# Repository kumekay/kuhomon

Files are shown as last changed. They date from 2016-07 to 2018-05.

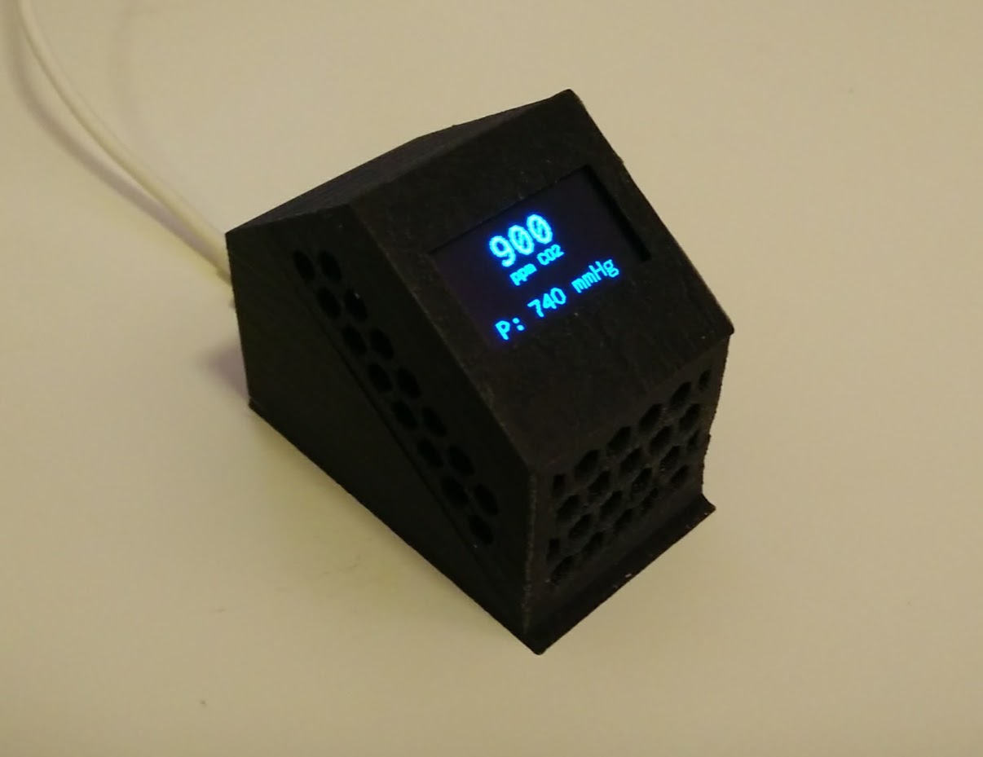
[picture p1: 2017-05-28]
demo.jpg

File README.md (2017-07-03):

# Kumekay Home Monitoring Device

System for measurement CO2/Humidity/Temperature/Pressure with OLED display and data upload through WiFi

If you want to use BME280 instead of SI7021+BMP085 take a look on [BME280 branch](https://github.com/pinya/kuhomon/tree/bme280)

## Discussion


## Components

- CO2 Sensor MH-Z19
- ESP8266 (NodeMCU ESP12+ based)
- SSD1306 0.96" 128x64 i2c OLED. Library: <https://github.com/olikraus/u8g2>
- Humidity/Temperature SI7021 i2c. Library: <https://github.com/LowPowerLab/SI7021>
- Pressure/Temperature BMP085 i2c. Library: <https://github.com/adafruit/Adafruit-BMP085-Library>

## Case

Model for printing kuhomon_case.stl

Known issues:
- To fit system to this case you have to use short wires
- Temperature measurements seems to be higher due to heat from ESP8266

## TODO
- Add offline support (show data on screen without WiFi)

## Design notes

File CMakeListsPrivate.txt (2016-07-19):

set(ENV{PATH} "/home/ku/.local/bin:/home/ku/bin:/home/ku/.rbenv/shims:/home/ku/.rbenv/bin:/home/ku/.local/bin:/home/ku/bin:/home/ku/.rbenv/shims:/home/ku/.rbenv/bin:/usr/local/sbin:/usr/local/bin:/usr/sbin:/usr/bin:/sbin:/bin:/usr/games:/usr/local/games:/snap/bin")
set(PLATFORMIO_CMD "/usr/local/bin/platformio")

include_directories("$ENV{HOME}/.platformio/packages/framework-arduinoespressif/variants/generic")
include_directories("$ENV{HOME}/.platformio/packages/framework-arduinoespressif/variants/nodemcu")
include_directories("$ENV{HOME}/.platformio/packages/framework-arduinoespressif/cores/esp8266")
include_directories("$ENV{HOME}/.platformio/packages/framework-arduinoespressif/cores/esp8266/libb64")
include_directories("$ENV{HOME}/.platformio/packages/framework-arduinoespressif/cores/esp8266/spiffs")
include_directories("$ENV{HOME}/.platformio/packages/framework-arduinoespressif/cores/esp8266/umm_malloc")
include_directories("$ENV{HOME}/.platformio/packages/framework-arduinoespressif/libraries/ESP8266WiFi/src")
include_directories("$ENV{HOME}/.platformio/packages/framework-arduinoespressif/libraries/ESP8266WiFi/src/include")
include_directories("$ENV{HOME}/.platformio/packages/framework-arduinoespressif/libraries/DNSServer/src")
include_directories("$ENV{HOME}/.platformio/packages/framework-arduinoespressif/libraries/ESP8266WebServer/src")
include_directories("$ENV{HOME}/.platformio/packages/framework-arduinoespressif/libraries/ESP8266WebServer/src/detail")
include_directories("$ENV{HOME}/.platformio/lib/WifiManager_ID567")
include_directories("$ENV{HOME}/.platformio/packages/framework-arduinoespressif/libraries/ESP8266HTTPClient/src")
include_directories("$ENV{HOME}/.platformio/packages/framework-arduinoespressif/libraries/ESP8266httpUpdate/src")
include_directories("$ENV{HOME}/.platformio/lib/Blynk_ID415/Adapters")
include_directories("$ENV{HOME}/.platformio/lib/Blynk_ID415/Blynk")
include_directories("$ENV{HOME}/.platformio/lib/Blynk_ID415")
include_directories("$ENV{HOME}/.platformio/lib/Blynk_ID415/utility")
include_directories("$ENV{HOME}/.platformio/lib/Json_ID64")
include_directories("$ENV{HOME}/.platformio/lib/Json_ID64/include")
include_directories("$ENV{HOME}/.platformio/lib/Json_ID64/include/ArduinoJson")
include_directories("$ENV{HOME}/.platformio/lib/Json_ID64/include/ArduinoJson/Internals")
include_directories("$ENV{HOME}/.platformio/lib/Json_ID64/include/ArduinoJson/Polyfills")
include_directories("$ENV{HOME}/.platformio/lib/Json_ID64/include/ArduinoJson/TypeTraits")
include_directories("$ENV{HOME}/.platformio/lib/Json_ID64/src/Internals")
include_directories("$ENV{HOME}/.platformio/lib/Json_ID64/src")
include_directories("$ENV{HOME}/.platformio/packages/framework-arduinoespressif/libraries/Wire")
include_directories("$ENV{HOME}/.platformio/packages/framework-arduinoespressif/libraries/SPI")
include_directories("$ENV{HOME}/Dropbox/kuhomon/lib/TFT_ILI9163C")
include_directories("$ENV{HOME}/Dropbox/kuhomon/lib/TFT_ILI9163C/_display")
include_directories("$ENV{HOME}/Dropbox/kuhomon/lib/TFT_ILI9163C/_fonts")
include_directories("$ENV{HOME}/Dropbox/kuhomon/lib/TFT_ILI9163C/_includes")
include_directories("$ENV{HOME}/Dropbox/kuhomon/lib/TFT_ILI9163C/_settings")
include_directories("$ENV{HOME}/.platformio/lib/Adafruit_DHT_ID19")
include_directories("$ENV{HOME}/.platformio/lib/SimpleTimer_ID419")
include_directories("$ENV{HOME}/.platformio/packages/framework-arduinoespressif/tools/sdk/include")
include_directories("$ENV{HOME}/.platformio/packages/framework-arduinoespressif/tools/sdk/lwip/include")
include_directories("$ENV{HOME}/Dropbox/kuhomon/src")
include_directories("$ENV{HOME}/.platformio/lib/Adafruit_BMP085_Unified_ID16")
include_directories("$ENV{HOME}/.platformio/lib/Adafruit_GFX_ID13")
include_directories("$ENV{HOME}/.platformio/lib/Adafruit_PCD8544_ID81")
include_directories("$ENV{HOME}/.platformio/lib/Adafruit_Unified_Sensor_ID31")
include_directories("$ENV{HOME}/.platformio/lib/Esp8266Configuration_ID227")
include_directories("$ENV{HOME}/.platformio/lib/Nanopb_ID431")
include_directories("$ENV{HOME}/.platformio/lib/PubSubClient_ID89/src")
include_directories("$ENV{HOME}/.platformio/lib/RTC_ID274/src")
include_directories("$ENV{HOME}/.platformio/lib/Task_ID272/src")
include_directories("$ENV{HOME}/.platformio/packages/framework-arduinoespressif/libraries/ArduinoOTA")
include_directories("$ENV{HOME}/.platformio/packages/framework-arduinoespressif/libraries/EEPROM")
include_directories("$ENV{HOME}/.platformio/packages/framework-arduinoespressif/libraries/ESP8266AVRISP/src")
include_directories("$ENV{HOME}/.platformio/packages/framework-arduinoespressif/libraries/ESP8266HTTPUpdateServer/src")
include_directories("$ENV{HOME}/.platformio/packages/framework-arduinoespressif/libraries/ESP8266SSDP")
include_directories("$ENV{HOME}/.platformio/packages/framework-arduinoespressif/libraries/ESP8266WiFiMesh/src")
include_directories("$ENV{HOME}/.platformio/packages/framework-arduinoespressif/libraries/ESP8266mDNS")
include_directories("$ENV{HOME}/.platformio/packages/framework-arduinoespressif/libraries/Ethernet/src")
include_directories("$ENV{HOME}/.platformio/packages/framework-arduinoespressif/libraries/GDBStub/src")
include_directories("$ENV{HOME}/.platformio/packages/framework-arduinoespressif/libraries/Hash/src")
include_directories("$ENV{HOME}/.platformio/packages/framework-arduinoespressif/libraries/SD/src")
include_directories("$ENV{HOME}/.platformio/packages/framework-arduinoespressif/libraries/Servo/src")
include_directories("$ENV{HOME}/.platformio/packages/framework-arduinoespressif/libraries/SoftwareSerial")
include_directories("$ENV{HOME}/.platformio/packages/framework-arduinoespressif/libraries/TFT_Touch_Shield_V2")
include_directories("$ENV{HOME}/.platformio/packages/framework-arduinoespressif/libraries/Ticker")
include_directories("$ENV{HOME}/.platformio/packages/framework-arduinoespressif/libraries/esp8266/src")
include_directories("$ENV{HOME}/.platformio/packages/toolchain-xtensa/xtensa-lx106-elf/include")
include_directories("$ENV{HOME}/.platformio/packages/toolchain-xtensa/lib/gcc/xtensa-lx106-elf/4.8.2/include")
include_directories("$ENV{HOME}/.platformio/packages/toolchain-xtensa/lib/gcc/xtensa-lx106-elf/4.8.2/include-fixed")

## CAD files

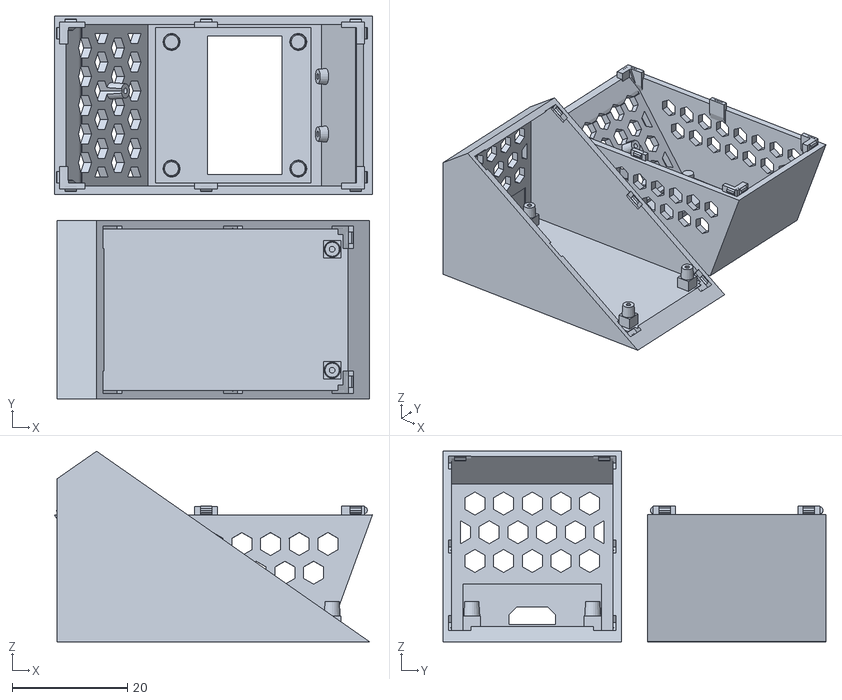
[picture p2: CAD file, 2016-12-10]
kuhomon_case.stl
55.2 x 66.5 x 33.1

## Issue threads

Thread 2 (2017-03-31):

плата висит в состоянии Loading...

zigithu, 2017-03-31:
Собрал схему только с одним датчиком (CO2 mh-z19). Загружается, по wifi доступна, на 192.168.4.1 заходит, но после конфигурирования параметров wifi плата перезагружается и висит в состоянии Loading...
В чем может быть причина? Возможно отсутствие датчиков приводит к зависанию? Возможно ли добавить проверку на отсутствие/смерть датчиков?

pinya, 2017-04-07:
Можете подключиться к serial консоле и прислать все, что выводится в процессе загрузки?

zigithu, 2017-04-10:
пока вот такие данные. Изменение кодировки не помогает
======================================
pio device monitor --port COM9 --baud 74880
--- Miniterm on COM9  74880,8,N,1 ---
--- Quit: Ctrl+C | Menu: Ctrl+T | Help: Ctrl+T followed by Ctrl+H ---

 ets Jan  8 2013,rst cause:2, boot mode:(3,6)

load 0x4010f000, len 1384, room 16
tail 8
chksum 0x2d
csum 0x2d
v09f0c112
~ld

pio device monitor --port COM9 --baud 115200
--- Miniterm on COM9  115200,8,N,1 ---
--- Quit: Ctrl+C | Menu: Ctrl+T | Help: Ctrl+T followed by Ctrl+H ---
r$␀dܞ|␀�l�|␃␌␌␄�␜�l�␌#|��␃�␓��|2c�␌#�p~�o�dno���␌#␜p��bd`␃rlp�o�␐␂␌␄�␄l␄��␌␄␌B␌N�|␂l�␌␄�p␄��oN�␃$��l ␃�␓2no␌d`␃␏␃or����␂␄␌b␌�␎$␎{��N␌␄#␄�␏l�␂l���␛$�$`␃��o�␃

pio device monitor --port COM9 --baud 9600
--- Miniterm on COM9  9600,8,N,1 ---
--- Quit: Ctrl+C | Menu: Ctrl+T | Help: Ctrl+T followed by Ctrl+H ---
␁␅^��␝q��

pinya, 2017-04-13:
Это нормальный вывод при загрузке, удивительно, что это все.
Отсутствие датчика CO2 и температуры/влажности не должно быть проблемой - просто будут возвращаться нули.
При отсутствии BMP в консоли должна быть строка `"Could not find a valid BMP085 sensor, check wiring!"`

Попробуйте, пожалуйста, еще раз собрать вывод консоли - не отключая плату от usb нажмите кнопку reset на плате. Вероятно там будет что-то еще
Скорость UART 115200

В начале там будет каша от загрузчика, он работает на другой скорости, но потом должен появиться вывод самой прошивки

Добавьте для проверки DEBUG_SERIAL.println("Start init...");` после строчки `        DEBUG_SERIAL.begin(115200);` в функции setup

zigithu, 2017-04-14:
Результат тот же. Дополнительной информации не появилось. При перезагрузке вываливает кучу мусора. При этом экран загорается и отображает стартовую станицу. Через веб то пускает то не пускает. В случае когда пускает: после указания учетных данных wifi сети подключается в точке доступа, на экране горит loading... и ничего не происходит.
Решил пока не мучить эту плату а подожду когда приедет esp-07. Попробую на ней.

pandability, 2017-05-22:
**zigithu**, у вас что нибудь получилось с этой или с новой платой? У меня такая же ситуация - после настройки wi-fi подключения плата висит в статусе Loading.

pandability, 2017-05-22:
Что то внятное выдало тоже только на скорости 74880, один раз увидел что boot mode:(3,7) было.

```
PORT OPEN 74880

Communication with MCU..Got answer! Communication with MCU established.
AutoDetect firmware...

Can't autodetect firmware, because proper answer not received (may be unknown firmware).
Please, reset module or continue.

 ets Jan  8 2013,rst cause:2, boot mode:(3,6)

load 0x4010f000, len 1384, room 16
tail 8
chksum 0x2d
csum 0x2d
v09f0c112
~ld
```

zigithu, 2017-05-23:
Заказал 2 платы на чипе 340.... жду больше месяца. Но я использовал свою NodeMCU в другом проекте и она там тоже работает, но очень нестабильно.
Следовательно она неисправна. но глюк плавающий - возможно надо пропаять и прогреть все контакты
PS
1)вот этот модуль глючит (v2) https://ru.aliexpress.com/item/New-Wireless-module-NodeMcu-Lua-WIFI-Internet-of-Things-development-board-based-ESP8266-with-pcb-Antenna/32593655688.html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
2) вот эти я ожидаю https://ru.aliexpress.com/item/ESP8266-CH340G-CH340-G-NodeMcu-V3-Lua-Wireless-WIFI-Module-Connector-Development-Board-Based-ESP-12E/32800966224.html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

pinya, 2017-05-23:
У меня есть несколько разных модулей, попробую на этой неделе повторить такое поведение

pinya, 2017-05-28:
Я совсем забыл, что в опубликованной версии кода для отладочной информации испльзуется другой serial порт, и нужен был еще один usb-uart, чтобы эти данные собирать.
Я это изменил (72074ee), теперь данные выводятся в основную консоль. Я не знаю есть ли проблема, описанная в этом issue, но по крайней мере debug вывод сейчас работает.
Завтра посмотрю подробнее.

pinya, 2017-06-01:
Я обновил код теперь он выводит больше информации в консоль и более детально отображает статус на экране + некоторые мелкие правки, которые вероятно решили проблему, поэтому прошу попробовать последнюю версию: 02580683aca0164042c28912a3c59f0fa347836b

zigithu, 2017-06-06:
Так, пришло время закрывать этот тикет. Мне наконец-то пришли мои платы (https://ru.aliexpress.com/item/ESP8266-CH340G-CH340-G-NodeMcu-V3-Lua-Wireless-WIFI-Module-Connector-Development-Board-Based-ESP-12E/32800966224.html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) они оказались абсолютно исправные за исключением того что судя по всему в них установлена более медленная флеш память не QUAD а DIO (вот тут можно посмотреть мой скриншот при прошивке через ESP Flash Tool). Как оказалось это не оригинальный AI-Thinker  а клон HYSIRY. Но тем не менее он работает. Я прошился прошивкой из ветки BME280. Как и **apan65** (https://github.com/pinya/kuhomon/issues/4) я попался на том что не указал blynk-токен. Для исправления ситуации в 421 строку вставил factoryReset(); перепрошился, потом убрал factoryReset(); и перепрошился еще раз. Датчик BME280 заработал отлично: показывает температуру влажность и атмосферное давление. А вот датчик Co2 я сжег когда перепаивал ему ноги(((((
PS 1) логи стали очень информативные. смотрятся на скорости 115200.
2) возможно на дисплей надо вывести тоже что и в консоли? сейчас:  drawBoot("Connecting...");         DEBUG_SERIAL.println("Connecting to blynk...");
сделать:  drawBoot("Connecting to blynk ...");         DEBUG_SERIAL.println("Connecting to blynk...");
или не влезет на экран?
3) в ветке BME280 не хватает библиотеки 166 и я так понимаю ненужные библиотеки: 536,525,16
Спасибо за ваш код. Было интересно. Пойду заказывать датчик(

pinya, 2017-07-03:
Рад, что у вас все получилось!

Closed 2017-07-03.

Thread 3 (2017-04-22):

bme-280 и датчик пыли GP2Y1014AU0F

kashaev, 2017-04-22:
Что необходимо поменять в коде, если я буду использовать bme-280 и датчик пыли GP2Y1014AU0F.

pinya, 2017-04-24:
А можно поподробнее в чем проблема? Кажется вы забыли добавить текст

pinya, 2017-04-24:
Если верить официальной схеме от sharp и вот этой инструкции, то вам еще понадобится резистор на 150 ом, и электролитический конденсатор на 220 мкФ (10в)
arduinodev.woofex.net/2012/12/01/standalone-sharp-dust-sensor

kashaev, 2017-04-25:
Прошу прощения, что трачу Ваше время. Насчёт необходимых элементов я понял. В ближайшее время приобрету.

pinya, 2017-05-19:
@kashaev добрый день, как успехи с модификацией? Что-нибудь вышло?

pinya, 2017-06-01:
@kashaev Если вы отказались от идеи делать версию с датчиком пыли, то я закрою этот вопрос

kashaev, 2017-06-12:
Здравствуйте! Очень много дел на работе и остается совсем мало свободного времени.. На данный момент я осваиваю азы программирования.  С 19 числа вплотную займусь этим вопросом. Все необходимые комплектующие у меня есть. Спасибо, что интересуетесь)

kashaev, 2017-06-28:
Здравствуйте! Прошу Вашего совета. Прибор собран, датчик пыли работает исправно. Проблема заключается в том, что он крайне не чувствителен. Нужно как следует дунуть в отверстие, чтоб он показал какие - либо цифры. Не калибровал. Есть идя поставить под него или на него что-то вроде кулера для тяги. Второй вопрос по поводу CO2: датчик показывает неадекватные значения, легко сбивается. Работает нормально только после повторной прошивки, но если выключить и включить снова сбивается. Не калибровал.

pinya, 2017-06-29:
По поводу датчика пыли не могу сказать, т.к. никогда им не пользовался. Он у вас с вентилятором для активной продувки или без?
Датчик CO2 имеет время прогрева около 3-5 минут, соответственно после включения первое время он показывает не совсем то. Если он у вас находится в квартире с периодическим проветриванием, то калибровать его не нужно.

kashaev, 2017-10-02:
Здравствуйте! Подскажите, пожалуйста,  можно ли самому создать приложение на ios, чтоб дублировать туда данные , приходящие на blynk? Элементарное одностраничное приложение, где будут просто показываться данные. Конструкторов приложений масса, но как их связать...

kumekay, 2017-10-02:
Можно из скетча отправлять данные не только в blynk, но и в какой-нибудь другой сервис при помощи http запроса. Вариантов слишком много, но какой-либо в пару кликов в голову не приходит. (я никогда не интересовался конструкторами приложение)
И еще вопрос в том, чем приложение blynk не подходит

kashaev, 2017-10-02:
Blynk подходит. Идея в том, что бы создать приложение немного с другим функционалом для группы людей, используя эти данные. Спасибо!

kumekay, 2017-10-02:
Ок, тогда будем считать этот вопрос закрытым

Closed 2017-10-02.

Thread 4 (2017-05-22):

Код для модификации с одним bme280 вместо пары bmp280+si702

pandability, 2017-05-22:
Добрый день.
Не будете ли вы столь любезны выложить вариант кода при использовании датчика BME280?
В силу того, что желание познакомиться с IoT возникло исключительно благодаря вашей статье про метеостанцию на GT, собственных сил и знаний пока не хватает.

pinya, 2017-05-23:
Добрый день, да я подготовлю вариант на этой неделе

apan65, 2017-05-24:
**pinya**, Отлично, как раз хотел сейчас с этим же вопросом обратиться. Буду ждать.

pinya, 2017-05-28:
Я пока не опубликовал этот вариант, т.к. навожу порядок в коде основной ветки. Сделаю в ближайшие несколько дней, после завершения #2

apan65, 2017-05-29:
C нетерпением ожидаю

pinya, 2017-06-01:
Опубликовал версию для BME280 в отдельной ветке:
https://github.com/pinya/kuhomon/tree/bme280

На руках у меня BME280 нет, чтобы проверить, но должно работать

apan65, 2017-06-01:
Такая беда
"IP address: 192.169.1.107
Load config...
Config loaded
blynk server: blynk-cloud.com
port: 8442
token: Blynk token
Connecting to blynk...
Connecting to blynk...
Connecting to blynk...
и тд, не может приконнектиться.
"

apan65, 2017-06-01:
Может это проблема роутера, с портами что-то?

pinya, 2017-06-01:
Проблема:
```
token: Blynk token
```
При настройке не указан токен blynk

Нужно сбросить на заводские настройки,
Вообще, Для сброса на заводские настройки нужно на время подсоединить GPIO 12 (D6) на землю, но здесь этот метод не сработает.
Я подумаю как это можно обойти.

Простая перепрошивка не поможет.

apan65, 2017-06-01:
> но здесь этот метод не сработает.
А чем вообще сброс теоретически может помочь и почему здесь этот метод не работает?

pinya, 2017-06-02:
При обычной перепрошивке данные подключения не удалятся, они хранятся в другой части памяти.
Как я уже писал, есть предусмотренный в прошивке метод для сброса на заводские настройки,

> Для сброса на заводские настройки нужно на время подсоединить GPIO 12 (D6) на землю,

Но этот метод не очень корректно организован, он работает, когда устройство полностью загружено. Здесь же оно останавливается в процессе загрузки.

Чтобы не ждать моего полноценного решения добавьте первой строкой в main.cpp в функцию `setup()` (строка 415) вызов   `factoryReset();`

```
void setup() {
  factoryReset();
```

Прошейте, подождите минутку,
потом удалите эту строчку и прошейте снова.
Это сработает

apan65, 2017-06-02:
Так, теперь работает, но с BME по нулям получает. Я его отдельно проверял, сенсор в порядке, может проблема с пинами?

pinya, 2017-06-02:
Я обновил код, можете прошить и прислать что он выводит в консоль после загрузки, при каждом измерении?

В моем случае:
```
Getting Temperature from SI7021
Getting Temperature from BMP085
Getting Humidity from SI7021
Getting Pressure from BMP085
Getting CO2
CO2:400
H: 41%
T: 28C
P: 742mmHg
CO2: 400ppm
```

apan65, 2017-06-02:
Всё так же
```
Getting Temperature from BME280
Getting Humidity from BME280
Getting Pressure from BME280
Getting CO2
CO2:710
H: 0.00%
T: 0.00C
P: 0.00mmHg
CO2: 710ppm

```

pinya, 2017-06-02:
Попробуйте сменить адрес в инициализации устройства. BME280 может работать на разных адресах.
в строке 439 укажите адрес 0x76 (по умолчанию 0x77)
```
        // Init Pressure/Temperature sensor
        if (!bme.begin(0x76)) {
                DEBUG_SERIAL.println("Could not find a valid BME280 sensor, check wiring!");
        }
```

Если это не поможет, то попробуйте посмотреть на каких адресах у вас вообще есть устройства,
это можно сделать при помощи вот этой прошивки:
https://playground.arduino.cc/Main/I2cScanner
Она выведет все i2c устройства в консоль

apan65, 2017-06-02:
Таки да, в адресе была проблема.

pinya, 2017-06-02:
Отлично, можно закрывать этот вопрос?

apan65, 2017-06-02:
Ага, огромное спасибо за помощь и идею для устройства.
Потом может парочка идей придет по улучшению функционала, отпишусь.

pinya, 2017-06-02:
Да, тут есть над чем поработать. Вероятно займусь новой версией в июле.
Удачи и спасибо за отзыв!

Closed 2017-06-02.

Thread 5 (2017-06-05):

BME280 в README.md

zigithu, 2017-06-05:
В ветке BME280 наверно в README.md

надо это
Humidity/Temperature SI7021 i2c. Library: https://github.com/LowPowerLab/SI7021
Pressure/Temperature BMP085 i2c. Library: https://github.com/adafruit/Adafruit-BMP085-Library

заменить вот на это
Humidity/Pressure/Temperature BME280        https://github.com/adafruit/Adafruit_BME280_Library

pinya, 2017-06-06:
Fixed in ee02863fa61568b8e211c38b9fcd5c51b8efa89d

Closed 2017-06-06.

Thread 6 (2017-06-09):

Добавить на главном экране иконки доступности блинка и подключения к wifi

pinya, 2017-06-09:
Добавить на главном экране иконки доступности блинка и подключения к wifi
при установлении связи иконки постоянно отображаются
При подключении к wifi вместо connecting wifi просто поморгать иконкой wifi
При подключении к blynk вместо connecting… просто поморгать иконкой blynk

zigithu, 2017-06-10:
к примеру вот так
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

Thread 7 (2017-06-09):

Отображать все значения на одном экране

kumekay, 2017-06-09:
Не очень удобно ждать около 10 секунд что бы увидеть все три текущих значения (T/P/H). Было бы круто увидеть все цифры на одном экране (без надобности ожидания пока обновится экран).
К примеру значения CO2 можно переместить в левую часть экрана а в правой части разместить в колонку все три значения (T/P/H)
примерно вот так
Wifi =ok blynk=ok
567 T= 23 oC
ppm CO2 H= 48%
P=739 mmHg

zigithu, 2017-06-10:
я имел ввиду что-то вроде этого:
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
Но лично для меня это уже не очень актуально - так как я планирую использовать датчик без дисплея.

kumekay, 2017-11-12:
Думаю, что этот вопрос можно закрыть

Closed 2017-11-12.

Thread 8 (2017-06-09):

Add offline support (show data on screen without WiFi)

pinya, 2017-06-09:

CadilVB, 2018-01-16:
Безусловно, автономная работа метеостанции сделает устройство функционально законченным.
Я реализовал режим автономной работы по алгоритму, который, как мне кажется, лежит  на поверхности:
ЕСЛИ  на заданном  pin'е  есть "1",  ТО автономная работа ИНАЧЕ работа в сети.
Этот алгоритм реализован в прилагаемом скетче.
В SETUP идентифицируются функции автономной работы по условию  if (digitalRead(display_pin) == HIGH) ...  else  ... идентификация функций  работы в сети. Аналогично по такому же условию вызываются функции в LOOP. Впрочем, из кода все станет понятно.
Скетч - работающий.  Достаточно подключить экран. Обратите внимание на пины подключения экрана. Датчики подключать не нужно - для тестирования работырежимов  заданы фиксированные значения  температуры, влажности и т.д.
Есть идея, как  автономную поддержку организовать более элегантно, но об этом поговорим позже, если будет интерес к теме ...
[OLED_Blynk_ON-OFF-line_1fin.zip](https://github.com/kumekay/kuhomon/files/1635117/OLED_Blynk_ON-OFF-line_1fin.zip)
...

kumekay, 2018-01-18:
Оффлайн режим лучше включать по таймауту при неудачи подключения к WiFi
Большая просьба, если хотите поделиться каким-нибудь кодом, то не прикладывайте его в zip-файлах, а создайте форк репозитория и внесите изменения туда,
или хотя бы на https://gist.github.com

nakuts, 2019-05-04:
Приветствую автора этого замечательного проекта, решил зделать ваш проект используя вашу статью на: https://habr.com/ru/post/400975/ "Код прошивки, чтобы не ходить на Github" скопировал и внёс в ардуино ide.
Даже получилось подобрать все библиотеки но в коде выдаёт ошибку: в строкеStaticJsonBuffer<200>
...................................
error: StaticJsonBuffer is a class from ArduinoJson 5. Please see arduinojson.org/upgrade to learn how to upgrade your program to ArduinoJson version 6
 StaticJsonBuffer<200> jsonBuffer;
DynamicJsonBuffer is a class from ArduinoJson 5. Please see arduinojson.org/upgrade to learn how to upgrade your program to ArduinoJson version 6
DynamicJsonBuffer jsonBuffer;
....................................

В платформео тоже не получилось докачать библиотеки
Помогите с проектом. :)

kumekay, 2019-05-06:
Попробуйт установить ArduinoJson версии 5, https://arduinojson.org/v5/doc/installation/

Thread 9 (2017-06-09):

Fix factory reset during setup()

pinya, 2017-06-09:

DimsterTim, 2018-02-04:
Я пробую повторить проект с BME280 и экраном ssd1306 32x128. Столкнулся со следующими проблемами. Не могу сбросить сохраненные токен Блинка и настроек WiFi. Как это сделать простейшим образом? При подключении к WiFi экран работает? А то у меня ничего не отображается.

DimsterTim, 2018-02-04:
Подключился к Блинку, в порт выдает только CO2, и то с ошибкой:
Getting Temperature from BME280
Getting Humidity from BME280
Getting Pressure from BME280
Getting CO2
CO2: Header not found
H: 0.00%
T: 0.00C
P: 0.00mmHg
CO2: 647ppm

kumekay, 2018-02-04:
> ssd1306 32x128

Точно не могу сказать какие проблемы могут быть из-за другого рамера экрана

> BME280
Проверьте i2c адрес на котором висит модуль, у bme280 поддерживает два адреса 0x77 и 0x76 - у разных модулей выбран разный. Попробуйте оба или посмотрите вообще виден ли ваш сенсор при помощи https://gist.github.com/tfeldmann/5411375

> CO2: Header not found
Разовая ошибка в начале это абсолютно нормально

kumekay, 2018-02-04:
> Не могу сбросить сохраненные токен Блинка и настроек WiFi

Добавьте на время  вызов `factoryReset()` в setup(), а после сброса удалите и перепрошейте заново

DimsterTim, 2018-02-04:
СО2 настроил, выдает показания - дело было в плохом соединении китайскими проводами. Что касается i2c устройств, то сканером они оба обнаруживаются, и работают по отдельности без отключения, но не работают вместе. Разбираюсь с адресацией в библиотеке u8g2.

DimsterTim, 2018-02-04:
Спасибо за советы! А то мне пришлось перепрошивать прошивкой NodeMCU и затирать флешку.

DimsterTim, 2018-02-06:
Так и не удается подружить OLED 128*32 с BME280.. не помогает и delay(100) в loop.. может pullup резюки добавить, так как на BME они распаяны, на экранчике скорее всего тоже, поэтому в параллеле сопротивление будет ниже. Что думаете, куда копать?

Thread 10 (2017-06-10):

Обсуждение и доработки проекта

zigithu, 2017-06-10:
Бесплатный blynk сервер предоставляет 2000 энергии. Я настроил blynk для этого проекта использовав 1700 энергии. Этого хватит для того чтобы ознакомиться с возможностями этого проекта без разворачивания своего собственного блинк сервера.
PS я собрал проект состоящий из одного датчика CO2 и одного датчика bme280.
пины для блинка:
V1- температура
V2 - влажность
V4 - давление
V5 - СО2
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

zigithu, 2017-06-10:
У меня вопрос к автору: зачем в предлагаемом вот здесь https://geektimes.ru/post/284994/ проекте блинка присутствует кнопка FW update.
Я так понимаю это обновление прошивки по воздуху. Зачем оно надо? и откуда оно прилетает... что-то в коде не смог найти этот момент.

pinya, 2017-07-03:
Перенес Blynk приложение в вики https://github.com/pinya/kuhomon/wiki/Blynk-application-QR-code

FW update позволяет загружать новую прошивку с указанного http адреса. В коде https://github.com/pinya/kuhomon/blob/master/src/main.cpp#L387-L411

Обсуждения давайте вести в Gitter-e https://gitter.im/kuhomon/Lobby#

Closed 2017-07-03.

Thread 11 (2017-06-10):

Проверенные комплектующие и магазины

zigithu, 2017-06-10:
1) **NodeMcu**
В них установлена более медленная флеш память не QUAD а DIO (пруф https://github.com/karawin/Ka-Radio/issues/13)
Как оказалось это не оригинальный AI-Thinker а клон (HYSIRY).
На данных платах на пине VIN нет 5В. Для запитки датчика CO2 я использовал пин VU (слева третий сверху).
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
покупал за 3,02$ вот здесь:
https://ru.aliexpress.com/item/ESP8266-CH340G-CH340-G-NodeMcu-V3-Lua-Wireless-WIFI-Module-Connector-Development-Board-Based-ESP-12E/32800966224.html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
На Windows10 с драйверами проблем не было - поставились автоматом.
2) **Temperature/Humidity/Barometric Pressure Sensor **bme280****
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
покупал вот тут: https://ru.aliexpress.com/item/Consumer-Electronics-Shop-Free-shipping-Digital-Temperature-Humidity-Barometric-Pressure-Sensor-Module-Breakout-BME280/32601813705.htm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
Покупал одну штуку за 4,89$, а продавец прислал 10 штук!!! Кто-нибудь проверьте была ли это ошибка продавца, или это норма. обязательно отпишитесь.

3) **MH-Z19 infrared co2 sensor**
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
покупал за 21,18$ вот здесь
https://ru.aliexpress.com/item/MH-Z19-infrared-co2-sensor-for-co2-monitor/32535524294.html?

4) **0.96 inch OLED I2C module 128X64**
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
покупал за 2,60$ вот здесь:
https://ru.aliexpress.com/item/1pcs-0-96-blue-0-96-inch-OLED-module-New-128X64-OLED-LCD-LED-Display-Module/32640627772.html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
особенность этого модуля: пины переставлены и названы по другому чем на этой схеме
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
GND = GND
VDD = VCC
SCK = SCL
SDA = SDA

pinya, 2017-07-03:
Перемещено в вики: https://github.com/pinya/kuhomon/wiki/RU-%D0%9F%D1%80%D0%BE%D0%B2%D0%B5%D1%80%D0%B5%D0%BD%D0%BD%D1%8B%D0%B5-%D0%BA%D0%BE%D0%BC%D0%BF%D0%BB%D0%B5%D0%BA%D1%82%D1%83%D1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

Closed 2017-07-03.

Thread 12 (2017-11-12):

Релехи

apan65, 2017-11-12:
Можно ли добавить функцию веб-интерфейсе чтобы выставлять значения температуры\влажности при которых будут срабатывать реле. Думаю функциональность очевидна очевидна.

apan65, 2017-11-12:
Плюс можно еще влажность и температуру на одном эране оставить. А давление неинформативно.

kumekay, 2017-11-12:
> Можно ли добавить функцию веб-интерфейсе чтобы выставлять значения температуры\влажности при которых будут срабатывать реле. Думаю функциональность очевидна очевидна.
Это возможно сделать прямо из мобильного приложения blynk при помощи компонента Eventor без изменения прошивки:
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

apan65, 2017-11-12:
Блин, реально, а я даже не вникал, просто графики повесил и забыл.

kumekay, 2017-11-12:
> Плюс можно еще влажность и температуру на одном эране оставить. А давление неинформативно.

Отображать информацию можно многими способами и универсального, подходящего для всех не существует. Возможность конфигурирования добавит ненужную сложность.

Closed 2017-11-12.

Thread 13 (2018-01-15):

Метеостанция - wdt reset!

CadilVB, 2018-01-15:
В свое время я с благодарностью воспользовался  советом **kumekay** и ввел   дополнительно несколько переменных, которые можно задать через Wi-Fi - по аналогии, например, с  переменной blynk_token в скетче метеостанции. Скетчи с новыми  переменными успешно работали.
Потом я занялся подключением других датчиков в схему метеостанции, но после  возврата к старым скетчам выяснилось, что они не работают. После загрузки в ESP - wdt reset.
В Инете прочитал, что причиной сообщения  wdt reset могут быть:
-  переполнение оперативной памяти,
- кривые или "прожорливые" библиотеки,
- кривой пользовательский код,,
- слишком навороченная программа, с которой ESP не справляется.
Два последних пункта отпадают - скетчи раньше работали.
В приложении - код метеостанции с добавлением новой переменной address.
В скетче я минимизировал количество переменных, чтобы уменьшить загрузку памяти. Глобальные переменные используют 39972 байт (48%) динамической памяти, оставляя 41948 байт для локальных переменных.
На мой взгляд, наиболее вероятной причиной этой проблемы является автообновление библиотек в  Arduino IDE, которое остановил с опозданием.
Я, конечно, тестировал скетч  со  старыми версиями некоторых библиотек, но как только расскомметирую строку 267:  strcpy(address, json["address"]) то все то же -  wdt reset. Как выйти на работающую комбинацию библиотек? - не представляю (если причина в комбинации).
Ниже - информация с монитора Arduino IDE при загрузке проблемного скетча.  Возможно она что-то прояснит.
Помогите решить проблему.

*WM: Adding parameter
*WM: blynk_token
*WM: Adding parameter
*WM: address
*WM:
*WM: AutoConnect
*WM: Connecting as wifi client...
*WM: Using last saved values, should be faster
*WM: Connection result:
*WM: 3
*WM: IP Address:
*WM: 192.168.1.100
WiFi connected
IP address: 192.168.1.100
Load config...

Exception (28):
epc1=0x4000bf0e epc2=0x00000000 epc3=0x00000000 excvaddr=0x00000000 depc=0x00000000

ctx: cont
sp: 3fff1010 end: 3fff1310 offset: 01a0

>>>stack>>>
3fff11b0:  3fffdad0 3fff022c 3fff2c3c 4020c5e9
3fff11c0:  3ffe89c8 3fff11c0 3fff11cc 3fff11dc
3fff11d0:  3fff2c3c 00000002 3fff2c49 00000000
3fff11e0:  3fff2c59 00000002 3fff2c65 40201c2c
3fff11f0:  00000018 00000008 3ffefae0 40201d40
3fff1200:  3fff004c 3ffefae0 3ffefb44 402015c9
3fff1210:  3fff1260 00000000 3ffefae0 4020ba34
3fff1220:  00000009 00000011 3fff022c 40201e06
3fff1230:  19082e00 00ffffff 0101a8c0 00000000
3fff1240:  00000007 0000000f 3ffefae0 40201ea3
3fff1250:  00000007 00000007 3ffefae0 4020ba64
3fff1260:  3ffeffec 00070010 3ffefae0 40201834
3fff1270:  3fff1c56 0000005a 3ffefae0 3fff02e8
3fff1280:  3fffdad0 00000010 3ffefae0 00000028
3fff1290:  3ffe94f0 00000000 000003e8 4010020c
3fff12a0:  3fff2bfc 3fff1c4c 3fff12d0 4010068c
3fff12b0:  3ffe889c 3ffe889c 3ffefae0 3fff02e8
3fff12c0:  3fffdad0 3ffe889c 3fff022c 4020d265
3fff12d0:  00000000 00000000 00000000 feefeffe
3fff12e0:  feefeffe feefeffe feefeffe 3fff02e8
3fff12f0:  3fffdad0 00000000 3fff02e0 4021537c
3fff1300:  feefeffe feefeffe 3fff02f0 40100718
<<<stack<<<

 ets Jan  8 2013,rst cause:2, boot mode:(1,3)

 ets Jan  8 2013,rst cause:4, boot mode:(1,3)

wdt reset

kumekay, 2018-01-18:
Добрый день,
Думаю, это из-за того что у вас  на чипе в SPIFFS уже сохранены настройки в которых нет ключа address.

Как вариант, добавьте временно сброс до заводских настроек первой строкой в setup, а после сброса удалите

```
void setup() {
  factoryReset();
```

CadilVB, 2018-01-18:
Фантастика! Без этой подсказки - я бы еще долго кувыркался. Успехов!

kumekay, 2018-01-18:
Спасибо, и вам

CadilVB, 2018-01-24:
Подскажите, пожалуйста, в какую библиотеку входит функция factoryReset()?

kumekay, 2018-01-24:
Она прямо в коде main.cpp

https://github.com/kumekay/kuhomon/blob/master/src/main.cpp#L104-L109

CadilVB, 2018-01-24:
Спасибо!
Извините за дилетантские вопросы. Инерция мышления - должен был сам проверить прежде, чем задавать вопрос.

CadilVB, 2018-02-04:
В метеостанции на основе скрипта kumekay с датчиком температуры и влажности DHT22, датчиком содержания CO2 MH-Z19 и отправкой данных на Blynk зависают показания MH-Z19, при этом, значения температуры и влажности отправляются на сервер Блинка нормально. После перезагрузки устройства информация с MH-Z19 снова нормально отправляется на Блинк и читается на экране 128*64 какое-то время, затем снова показания с MH-Z19 "замерзают".
Детали - [тут](https://esp8266.ru/forum/threads/zavisaet-mh-z19.3140/).
Тема висит с пятницы, но до сих пор - ни одного ответа по существу.
Помогите, пожалуйста, в очередной раз!

kumekay, 2018-02-04:
Вам нужно дожидаться начала пакета данных от сенсора. Либо скопируйте из моего кода
https://github.com/kumekay/kuhomon/blob/master/src/main.cpp#L123-L128
либо используйте
Serial.readBytesUntil() (https://www.arduino.cc/reference/en/language/functions/communication/serial/readbytesuntil/)

CadilVB, 2018-02-10:
Использовал вашу функцию readCO2() в целом. К сожалению, положительного результата не добился - метеостанция работает не более 3 часов без перезагрузки. На мой взгляд, условие поиска старта пакета по сути похоже на  проверку контр. суммы.
Протестировал другие [подходы](https://esp8266.ru/forum/threads/zavisaet-mh-z19.3140/#post-47644) - безрезультатно.
И еще. Рекомендованный период обращения к датчику MH Z-19 - не менее 10 сек.  Организовал цикл, в котором считывание данных с DHT - 1 сек, а с MH Z-19 - 20 сек  - не помогло.
Что думаете?

kumekay, 2018-02-10:
Думаю, что где-то течет память. Может в моем коде (что вероятнее), может в библиотеках. Нужно будет повнимательнее мне глянуть

CadilVB, 2018-02-12:
Прошу прощения, но я заблуждался, поверив то, что решение найдено после 24 часов работы простого скетча, в котором разнесено считывание с датчика и отправка на сервер, датчик
 подключен непосредственно к UART без библиотеки SoftwareSerial.h и добавлено условие поиска старта пакета считывания данных с датчика. Оказалось, что сутки работы - это мало, чтобы делать однозначный вывод.
Метеостанция kumekay,  с этими решениями проработала без малого 2 суток.
Сейчас отформатировал память модуля и загрузил простой скетч, который раньше проработал сутки. После нескольких ресетов (откл/вкл питания) скетч работает  6 часов. Перед этим после каждого ресета скетч работал 0,5...1 час.  Буду ждать очередного зависания, но то, что проблема не в коде метеостанции  - это очевидно. К тому же, судя по скринам в статье, метеостанция беспрерывно проработала по крайней мере 10 суток.

Ниже код загруженного скетча. Вас  что-то в нем настораживает?

`//скетч проработал без сбоев больше 24 часов
#define BLYNK_PRINT Serial    // Comment this out to disable prints and save space
#include <ESP8266WiFi.h>
#include <BlynkSimpleEsp8266.h>
//#include <SoftwareSerial.h>
//SoftwareSerial mySerial(13, 15); // GPIO15 (TX) and GPIO13 (RX)
#define mySerial Serial

char auth[] = "b0bf3e0d02f648c6b7aff07028хххххх";

//static byte cmd[9] = {0xFF,0x01,0x86,0x00,0x00,0x00,0x00,0x00,0x79}; //команда читання
//byte response[9];
byte cmd[9] = {0xFF,0x01,0x86,0x00,0x00,0x00,0x00,0x00,0x79};
unsigned char response[7];
byte crc = 0;
int co2, ppm;
int i = 0;

//kuh
void readCO2() {
        // CO2
        bool header_found {false};
      //  char tries {0};

        mySerial.write(cmd, 9);
        memset(response, 0, 7);

        // Looking for packet start
        while(mySerial.available() && (!header_found)) {
                if(mySerial.read() == 0xff ) {
                        if(mySerial.read() == 0x86 ) header_found = true;
                }
        }

        if (header_found) {
                mySerial.readBytes(response, 7);

                byte crc = 0x86;
                for (char i = 0; i < 6; i++) {
                        crc+=response[i];
                }
                crc = 0xff - crc;
                crc++;

                if ( !(response[6] == crc) ) {
                        Serial.println("CO2: CRC error: " + String(crc) + " / "+ String(response[6]));
                } else {
                        unsigned int responseHigh = (unsigned int) response[0];
                        unsigned int responseLow = (unsigned int) response[1];
                        unsigned int ppm = (256*responseHigh) + responseLow;
                        co2 = ppm;
                        Serial.println("CO2:" + String(co2));
                }
        } else {
                Serial.println("CO2: Header not found");
        }
}

/* void readCO2()
{
  while (mySerial.available())mySerial.read();//очистка буфера UART перед запросом
  memset(response, 0, 9);// очистка ответа
  mySerial.write(cmd,9);// запрос
  mySerial.readBytes(response, 9);//чтение 9 байт сенсора
  //расчет CRC
  crc = 0;
  for (int i = 1; i <= 7; i++)
  {
    crc += response[i];
  }
  crc = ((~crc)+1);
  {
  //проверка CRC
  if ( !(response[0] == 0xFF && response[1] == 0x86 && response[8] == crc) )
  {
    Serial.println("CRC error");
  } else
      {

      ppm = (((unsigned int) response[2])<<8) + response[3];

        Blynk.virtualWrite(V4, ppm);
        Serial.println("CO2: " + String(ppm) + "ppm");
        }
  }
}  */

void setup()
{
   mySerial.begin(9600);
   Serial.begin(9600);

Blynk.begin(auth, "ххххххххх", "ххххххххх", "blynk-cloud.com", 8442);
}

void loop(){
   Blynk.run();
   i++;
   Serial.println("time: " + String(i) + " *10s");
if (i>=60)  i = 0;
   readCO2();
   Blynk.virtualWrite(V4, co2);
   delay(10000);
}`

kumekay, 2018-02-13:
Код выглядит в порядке. Может что-то из библиотек?

Closed 2018-01-18.

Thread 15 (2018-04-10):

Fritzing - проблемы с компонентами

CadilVB, 2018-04-10:
Сергей,  снова обращаюсь к вам за помощью.
Решил нарисовать эл. схему своего макета. Мне понравился ваш стиль схемы, сделанный  в Fritzing, - наглядно и информативно. Начал искать для этой платформы новые компоненты, но безуспешно.
Меня интересуют следующие компоненты:
WiFi NodeMCU board ESP8266 (CP2102)
MH-Z19 - датчик содержания углекислого газа
DHT22 - датчик температуры и влажности
OLED LCD 0.96 (32*128) - дисплей
Two-way 4-channel converter of logic levels 3.3-5V
RF 433MHz transmitter
RF 433MHz  приемник
Зарегистрировался на http://forum.fritzing.org, но там процессы очень вялотекущие.
**Подскажите, пожалуйста, ссылку на новые компоненты Fritzing или поделитесь своей библиотекой.** Заранее благодарен.

kumekay, 2018-04-10:
На самом деле fritzing я использовал только один раз - как раз для той статьи.
Пользовался в основном компонентами из https://github.com/adafruit/Fritzing-Library
https://github.com/roman-minyaylov/fritzing-parts

Компонент для mh-z19 я делал сам, но к сожалению, не могу найти его сейчас

CadilVB, 2018-04-11:
Вы были правы - компоненты, которые не нашел в нете, оказалось проще создать самому, чем тратить время на поиски.
Успехов!

Closed 2018-04-10.

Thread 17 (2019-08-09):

MH-Z19B 'CO2: Header not found'

ulenspegel, 2019-08-09:
Добрый день!
Собрал прибор с датчиком MH-1Z9B на плате Node-MCU V3.
Пару часов все работает в норме, данные приходят, лишь иногда проскакивает 'CO2: Header not found', что, как я понимаю, совершенно нормально.
Однако через пару часов датчик зависает, данные не приходят, все время выдается 'CO2: Header not found'. При этом сам датчик продолжает работать, загорается красным как положено. Остальные датчики работают хорошо.
Выключение-включение ни к чему не приводит, перезагрузка скетча, обнуление EEPROM тоже не помогают, прибор после этого продолжает выдавать -1

kumekay, 2019-08-09:
Добрый день,
Какую прошивку вы используете? Последнюю из этого репозитория?
Напишите, пожалуйста, код вашей функции readCO2

ulenspegel, 2019-08-09:
Честно говоря, я затрудняюсь сказать какая прошивка, давно все это было. Скорее всего последнюю из репозитория.

А вот код:
void readCO2() {
        // CO2
        bool header_found {false};

        SENSOR_SERIAL.write(cmd, 9);
        memset(response, 0, 7);

        // Looking for packet start
        while(SENSOR_SERIAL.available() && (!header_found)) {
                if(SENSOR_SERIAL.read() == 0xff ) {
                        if(SENSOR_SERIAL.read() == 0x86 ) header_found = true;
                }
        }

        if (header_found) {
                SENSOR_SERIAL.readBytes(response, 7);

                byte crc = 0x86;
                for (char i = 0; i < 6; i++) {
                        crc+=response[i];
                }
                crc = 0xff - crc;
                crc++;

                if ( !(response[6] == crc) ) {
                        DEBUG_SERIAL.println("CO2: CRC error: " + String(crc) + " / "+ String(response[6]));
                } else {
                        unsigned int responseHigh = (unsigned int) response[0];
                        unsigned int responseLow = (unsigned int) response[1];
                        unsigned int ppm = (256*responseHigh) + responseLow;
                        co2 = ppm;
                        DEBUG_SERIAL.println("CO2:" + String(co2));
                }
        } else {
                DEBUG_SERIAL.println("CO2: Header not found");
        }

}

kumekay, 2019-08-13:
Выглядит нормально. Точно все в порядке с проводами? С каким-нибудь другим кодом, например через usb-uart с компьютера?
(Вот один из проектов https://github.com/fedulovivan/mhz19b)

kumekay, 2019-08-13:
Я пока закрою этот вопрос, если все-таки проблема именно с прошивкой, переоткройте, пожалуйста.

Closed 2019-08-13.

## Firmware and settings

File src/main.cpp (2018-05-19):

#include <FS.h>
#include <Arduino.h>
#include <ESP8266WiFi.h>          //https://github.com/esp8266/Arduino

// Wifi Manager
#include <DNSServer.h>
#include <ESP8266WebServer.h>
#include <WiFiManager.h>         //https://github.com/tzapu/WiFiManager

// HTTP requests
#include <ESP8266HTTPClient.h>

// OTA updates
#include <ESP8266httpUpdate.h>
// Blynk
#include <BlynkSimpleEsp8266.h>

// Debounce
#include <Bounce2.h> //https://github.com/thomasfredericks/Bounce2

// JSON
#include <ArduinoJson.h>          //https://github.com/bblanchon/ArduinoJson

// GPIO Defines
#define I2C_SDA 5 // D1 Orange
#define I2C_SCL 4 // D2 Yellow
#define HW_RESET 12

// Debounce interval in ms
#define DEBOUNCE_INTERVAL 10

Bounce hwReset {Bounce()};

// Humidity/Temperature SI7021
#include <SI7021.h>
SI7021 si7021;

#include <Wire.h>

// Pressure and Temperature
#include <Adafruit_BMP085.h>

// Use U8g2 for i2c OLED Lib
#include <SPI.h>
#include <U8g2lib.h>
U8G2_SSD1306_128X64_NONAME_F_SW_I2C u8g2(U8G2_R0, I2C_SCL, I2C_SDA, U8X8_PIN_NONE);
byte x {0};
byte y {0};

// Handy timers
#include <SimpleTimer.h>

// SW Serial
#include <SoftwareSerial.h>

SoftwareSerial swSer(13, 15, false, 256); // GPIO15 (TX) and GPIO13 (RX)

// CO2 SERIAL
#define DEBUG_SERIAL Serial
#define SENSOR_SERIAL swSer

byte cmd[9] = {0xFF,0x01,0x86,0x00,0x00,0x00,0x00,0x00,0x79};
unsigned char response[7];

// Pressure and temperature
Adafruit_BMP085 bme;

// Blynk token
char blynk_token[33] {"Blynk token"};
char blynk_server[64] {"blynk-cloud.com"};
const uint16_t blynk_port {8442};

// Device Id
char device_id[17] = "Device ID";
const char fw_ver[17] = "0.1.0";

// Handy timer
SimpleTimer timer;

// Setup Wifi connection
WiFiManager wifiManager;

// Network credentials
String ssid { "ku_" +  String(ESP.getChipId())};
String pass {"ku_" + String(ESP.getFlashChipId()) };

//flag for saving data
bool shouldSaveConfig = false;

// Sensors data
int t {-100};
int p {-1};
int h {-1};
int co2 {-1};

char loader[4] {'.'};

//callback notifying the need to save config
void saveConfigCallback() {
        DEBUG_SERIAL.println("Should save config");
        shouldSaveConfig = true;
}

void factoryReset() {
        DEBUG_SERIAL.println("Resetting to factory settings");
        wifiManager.resetSettings();
        SPIFFS.format();
        ESP.reset();
}

void printString(String str) {
        DEBUG_SERIAL.println(str);
}

void readCO2() {
        // CO2
        bool header_found {false};

        SENSOR_SERIAL.write(cmd, 9);
        memset(response, 0, 7);

        // Looking for packet start
        while(SENSOR_SERIAL.available() && (!header_found)) {
                if(SENSOR_SERIAL.read() == 0xff ) {
                        if(SENSOR_SERIAL.read() == 0x86 ) header_found = true;
                }
        }

        if (header_found) {
                SENSOR_SERIAL.readBytes(response, 7);

                byte crc = 0x86;
                for (char i = 0; i < 6; i++) {
                        crc+=response[i];
                }
                crc = 0xff - crc;
                crc++;

                if ( !(response[6] == crc) ) {
                        DEBUG_SERIAL.println("CO2: CRC error: " + String(crc) + " / "+ String(response[6]));
                } else {
                        unsigned int responseHigh = (unsigned int) response[0];
                        unsigned int responseLow = (unsigned int) response[1];
                        unsigned int ppm = (256*responseHigh) + responseLow;
                        co2 = ppm;
                        DEBUG_SERIAL.println("CO2:" + String(co2));
                }
        } else {
                DEBUG_SERIAL.println("CO2: Header not found");
        }

}

void sendMeasurements() {
        // Read data
        // Temperature
        printString("Getting Temperature from SI7021");
        float tf = si7021.getCelsiusHundredths() / 100.0;
        printString("Getting Temperature from BMP085");
        float t2f =bme.readTemperature();
        t = static_cast<int>((tf + t2f) / 2);

        // Humidity
        printString("Getting Humidity from SI7021");
        h = si7021.getHumidityPercent();

        // Pressure (in mmHg)
        printString("Getting Pressure from BMP085");
        p = static_cast<int>(bme.readPressure() * 760.0 / 101325);

        // CO2
        printString("Getting CO2");
        readCO2();

        // Send to server
        Blynk.virtualWrite(V1, t);
        Blynk.virtualWrite(V2, h);
        Blynk.virtualWrite(V4, p);
        Blynk.virtualWrite(V5, co2);

        // Write to debug console
        printString("H: " + String(h) + "%");
        printString("T: " + String(t) + "C");
        printString("P: " + String(p) + "mmHg");
        printString("CO2: " + String(co2) + "ppm");
}


void loading() {
        long unsigned int count {(millis() / 500) % 4};
        memset(loader, '.', count);
        memset(&loader[count], 0, 1);
}

void draw() {
        u8g2.clearBuffer();

        // CO2
        if (co2 > -1) {
                char co2a [5];
                sprintf (co2a, "%i", co2);

                u8g2.setFont(u8g2_font_inb19_mf);
                x = (128 - u8g2.getStrWidth(co2a))/2;
                y = u8g2.getAscent() - u8g2.getDescent();
                u8g2.drawStr(x, y, co2a);

                const char ppm[] {"ppm CO2"};
                u8g2.setFont(u8g2_font_6x12_mf);
                x = (128 - u8g2.getStrWidth(ppm)) / 2;
                y = y + 2 + u8g2.getAscent() - u8g2.getDescent();
                u8g2.drawStr(x, y, ppm);
        } else {
                loading();
                u8g2.setFont(u8g2_font_inb19_mf);
                x = (128 - u8g2.getStrWidth(loader)) / 2;
                y = u8g2.getAscent() - u8g2.getDescent();
                u8g2.drawStr(x, y, loader);
        }

        // Cycle other meauserments
        String measurement {"..."};
        const char degree {176};

        // Switch every 3 seconds
        switch((millis() / 3000) % 3) {
        case 0:
                if (t > -100) { measurement = "T: " + String(t) + degree + "C"; }
                break;
        case 1:
                if (h > -1) { measurement = "H: " + String(h) + "%"; }
                break;
        default:
                if (p > -1) { measurement =  "P: " + String(p) + " mmHg"; }
        }

        char measurementa [12];
        measurement.toCharArray(measurementa, 12);

        u8g2.setFont(u8g2_font_9x18_mf);
        x = (128 - u8g2.getStrWidth(measurementa))/2;
        y = 64 + u8g2.getDescent();
        u8g2.drawStr(x, y, measurementa);

        u8g2.sendBuffer();
}

void drawBoot(String msg = "Loading...") {
        u8g2.clearBuffer();
        u8g2.setFont(u8g2_font_9x18_mf);
        x = (128 - u8g2.getStrWidth(msg.c_str())) / 2;
        y = 32 + u8g2.getAscent() / 2;
        u8g2.drawStr(x, y, msg.c_str());
        u8g2.sendBuffer();
}

void drawConnectionDetails(String ssid, String pass, String url) {
        String msg {""};
        u8g2.clearBuffer();

        msg = "Connect to WiFi:";
        u8g2.setFont(u8g2_font_7x13_mf);
        x = (128 - u8g2.getStrWidth(msg.c_str())) / 2;
        y = u8g2.getAscent() - u8g2.getDescent();
        u8g2.drawStr(x, y, msg.c_str());

        msg = "net: " + ssid;
        x = (128 - u8g2.getStrWidth(msg.c_str())) / 2;
        y = y + 1 + u8g2.getAscent() - u8g2.getDescent();
        u8g2.drawStr(x, y, msg.c_str());

        msg = "pw: "+ pass;
        x = (128 - u8g2.getStrWidth(msg.c_str())) / 2;
        y = y + 1 + u8g2.getAscent() - u8g2.getDescent();
        u8g2.drawStr(x, y, msg.c_str());

        msg = "Open browser:";
        x = (128 - u8g2.getStrWidth(msg.c_str())) / 2;
        y = y + 1 + u8g2.getAscent() - u8g2.getDescent();
        u8g2.drawStr(x, y, msg.c_str());

        // URL
        // u8g2.setFont(u8g2_font_6x12_mf);
        x = (128 - u8g2.getStrWidth(url.c_str())) / 2;
        y = y + 1 + u8g2.getAscent() - u8g2.getDescent();
        u8g2.drawStr(x, y, url.c_str());

        u8g2.sendBuffer();
}

bool loadConfig() {
        DEBUG_SERIAL.println("Load config...");
        File configFile = SPIFFS.open("/config.json", "r");
        if (!configFile) {
                DEBUG_SERIAL.println("Failed to open config file");
                return false;
        }

        size_t size = configFile.size();
        if (size > 1024) {
                DEBUG_SERIAL.println("Config file size is too large");
                return false;
        }

        // Allocate a buffer to store contents of the file.
        std::unique_ptr<char[]> buf(new char[size]);

        // We don't use String here because ArduinoJson library requires the input
        // buffer to be mutable. If you don't use ArduinoJson, you may as well
        // use configFile.readString instead.
        configFile.readBytes(buf.get(), size);

        StaticJsonBuffer<200> jsonBuffer;
        JsonObject &json = jsonBuffer.parseObject(buf.get());

        if (!json.success()) {
                DEBUG_SERIAL.println("Failed to parse config file");
                return false;
        }

        // Save parameters
        strcpy(device_id, json["device_id"]);
        strcpy(blynk_server, json["blynk_server"]);
        strcpy(blynk_token, json["blynk_token"]);
}

void configModeCallback (WiFiManager *wifiManager) {
        String url {"http://192.168.4.1"};
        printString("Connect to WiFi:");
        printString("net: " + ssid);
        printString("pw: "+ pass);
        printString("Open browser:");
        printString(url);
        printString("to setup device");

        drawConnectionDetails(ssid, pass, url);
}

void setupWiFi() {
        //set config save notify callback
        wifiManager.setSaveConfigCallback(saveConfigCallback);

        // Custom parameters
        WiFiManagerParameter custom_device_id("device_id", "Device name", device_id, 16);
        WiFiManagerParameter custom_blynk_server("blynk_server", "Blynk server", blynk_server, 64);
        WiFiManagerParameter custom_blynk_token("blynk_token", "Blynk token", blynk_token, 34);
        wifiManager.addParameter(&custom_blynk_server);
        wifiManager.addParameter(&custom_blynk_token);
        wifiManager.addParameter(&custom_device_id);

        // wifiManager.setTimeout(180);
        wifiManager.setAPCallback(configModeCallback);

        if (!wifiManager.autoConnect(ssid.c_str(), pass.c_str())) {
                DEBUG_SERIAL.println("failed to connect and hit timeout");
        }

        //save the custom parameters to FS
        if (shouldSaveConfig) {
                DEBUG_SERIAL.println("saving config");
                DynamicJsonBuffer jsonBuffer;
                JsonObject &json = jsonBuffer.createObject();
                json["device_id"] = custom_device_id.getValue();
                json["blynk_server"] = custom_blynk_server.getValue();
                json["blynk_token"] = custom_blynk_token.getValue();


                File configFile = SPIFFS.open("/config.json", "w");
                if (!configFile) {
                        DEBUG_SERIAL.println("failed to open config file for writing");
                }

                json.printTo(DEBUG_SERIAL);
                json.printTo(configFile);
                configFile.close();
                //end save
        }

        //if you get here you have connected to the WiFi
        DEBUG_SERIAL.println("WiFi connected");

        DEBUG_SERIAL.print("IP address: ");
        DEBUG_SERIAL.println(WiFi.localIP());
}

// Virtual pin update FW
BLYNK_WRITE(V22) {
        if (param.asInt() == 1) {
                DEBUG_SERIAL.println("Got a FW update request");

                char full_version[34] {""};
                strcat(full_version, device_id);
                strcat(full_version, "::");
                strcat(full_version, fw_ver);

                t_httpUpdate_return ret = ESPhttpUpdate.update("http://romfrom.space/get", full_version);
                switch (ret) {
                case HTTP_UPDATE_FAILED:
                        DEBUG_SERIAL.println("[update] Update failed.");
                        break;
                case HTTP_UPDATE_NO_UPDATES:
                        DEBUG_SERIAL.println("[update] Update no Update.");
                        break;
                case HTTP_UPDATE_OK:
                        DEBUG_SERIAL.println("[update] Update ok.");
                        break;
                }

        }
}

// Virtual pin reset settings
BLYNK_WRITE(V23) {
        factoryReset();
}

void setup() {
        // Init serial ports
        DEBUG_SERIAL.begin(115200);
        SENSOR_SERIAL.begin(9600);

        // Init I2C interface
        Wire.begin(I2C_SDA, I2C_SCL);

        // Setup HW reset
        pinMode(HW_RESET,INPUT_PULLUP);
        hwReset.interval(DEBOUNCE_INTERVAL);
        hwReset.attach(HW_RESET);

        // Init display
        u8g2.begin();
        drawBoot();

        // Init Humidity/Temperature sensor
        si7021.begin(I2C_SDA, I2C_SCL);

        // Init Pressure/Temperature sensor
        if (!bme.begin()) {
                DEBUG_SERIAL.println("Could not find a valid BMP085 sensor, check wiring!");
        }

        // Init filesystem
        if (!SPIFFS.begin()) {
                DEBUG_SERIAL.println("Failed to mount file system");
                ESP.reset();
        }

        // Setup WiFi
        drawBoot("WiFi...");
        setupWiFi();

        // Load config
        drawBoot();
        if (!loadConfig()) {
                DEBUG_SERIAL.println("Failed to load config");
                factoryReset();
        } else {
                DEBUG_SERIAL.println("Config loaded");
        }

        // Start blynk

        Blynk.config(blynk_token, blynk_server, blynk_port);
        DEBUG_SERIAL.print("blynk server: ");
        DEBUG_SERIAL.println(  blynk_server );
        DEBUG_SERIAL.print("port: " );
        DEBUG_SERIAL.println(  blynk_port );
        DEBUG_SERIAL.print("token: " );
        DEBUG_SERIAL.println(  blynk_token  );

        drawBoot("Connecting...");
        DEBUG_SERIAL.println("Connecting to blynk...");
        while (Blynk.connect() == false) {
          delay(500);
          DEBUG_SERIAL.println("Connecting to blynk...");
        }

        // Setup a function to be called every 10 second
       timer.setInterval(10000L, sendMeasurements);

        sendMeasurements();
}

void loop() {
        Blynk.run();
        timer.run();
        draw();

        hwReset.update();
        if (hwReset.fell()) {
           factoryReset();
         }
}

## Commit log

2016-06-14 add BMP sensor, fix libraries
    [main.cpp]
2016-10-23 change display to i2c OLED
2016-12-10 Add case 3d model
    [kuhomon_case.stl]
2017-05-28 Use software serial for CO2 sensor
    [kuhomon.fzz]
2017-06-01 Add hw reset button, more wordy debug info
